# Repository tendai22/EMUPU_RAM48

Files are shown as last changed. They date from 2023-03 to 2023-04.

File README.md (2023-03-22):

# EMUPU_RAM48
A retroCPU companion board, inspired by Denno-Densetsu EMUZ80 and its related/inspired works

PIC18F, 128kB SRAMといにしえのCPUを用いて、いにしえのCPUを動作させます。Z80ピンアサインを基本にしていますが、基板上部にレトロCPUを載せた小型基板(メザニン基板)を繋ぐことで、Z80以外のさまざまなCPUに対応できるようにします。

PIC18F57Q43のCLC(Configurable Logic Cell)を活かしてCPU/SRAM制御信号を生成することで、最高パフォーマンスを目指します。そのために、アクセスタイム12nsのSRAMを使用します。48pin PICでピン数を稼いで、SPI経由でSDカードを駆動することも目標とする。

回路的には[奥江さんの作品](https://github.com/satoshiokue/SuperMEZ80)に由来しています。但し、奥江さんの作品は[EMUZ80](https://github.com/vintagechips/emuz80)基板をベースにしておりメザニン基板上でSRAMとCPUを搭載するのに対し、この試みでは、SRAMをメイン基板に移し、メザニン基板上にはCPUだけを載せるようにしています。

## コンセプト

* レトロCPUのプログラムはSRAM上に展開する。
* レトロCPUのプログラム展開はPICが行う(ブートローディング機能)。
* レトロCPUからSRAMへのアクセスは、/OE, /WEで行うが、これらの信号はPICのCLCで生成する。
* レトロCPUのI/OアクセスはPICで受ける。タイミング合わせのため、バスサイクルを延長する。
* バスサイクルの延長: Z80の場合は/WAIT信号による。68008の場合は/DTACKを使う。いずれもCLCでソフトウェア介在なしで発生する。
* I/O空間にはシリアル(Data, Status)、ディスクアクセス用のポートを置く。
* 割り込み発生とアクノレッジサイクル対応もPICが行う。

## CLCの使い方

SRAMの/OE, /WEをCLCでハード的に(ソフトを介在する必要なしに)発生する。これにより、SRAMアクセス時はソフト処理のオーバヘッドなしにZ80のメモリサイクルを実行させることができる。

I/Oアクセスは従来通り、PICがZ80のI/Oサイクルに対応する。/IORQで/WAIT信号をアサートし、I/OアクセスでCPUはアクセスを延長する。このやり方により、I/Oアクセスは時間が掛かる(数us～10数us程度)が、Z80プログラムの実行速度の大部分はメモリアクセスによるため、パフォーマンス低下の影響は小さいとしてよいだろう。

PIC側ソフトでI/O処理を行い、完了すると/BUSRQを立てて/WAITをネゲートする。CPUがI/Oサイクルを終了する(/IORQを監視している)と、/BUSRQを落としてCPUの実行を再開させる。/BUSRQをこのように使うことで、PIC側のサイクル終了処理を完了させるまでZ80を次のサイクルに入れないようにすることができる。

* CLCは3個使用する。それぞれで /OE, /WE, /WAITを発生する。
* /OE = /MREQ == 0 && /RD == 0 && /RFSH == 1
* /WE = /MREQ == 0 && /RD == 1 && /RFSH == 1
* /WAIT は/IORQの下りエッジでセットされるD-FFの/Q出力をあてる。

CLC1,2,3を使用し、それぞれの出力を、CLC1: /OE, CLC2: /WE, CLC3: /WAIT と割り当てる。

CLC1, CLC2は 4input AND, CLC3は D-FF with R/S とする。

CLC全セルの入力は最大8本で、RA/RCから4本、RB/RDから4本割り当てることができる。RE, RFからの割り当てはできない。この制約を考慮すると、
* Z80の出力, PICの入力: RA, RBに割り当てる。
* Z80の入力, PICの出力: RE(ソフト制御), RA or RB (CLC出力)

に割り当てるという原則ができる。

CLC1, CLC2の入力は、/MREQ, /RD, /RFSH であり、それぞれ RA1, RA4, RA5 に接続する。

CLC3の D-FF CLKに /IORQ を割り当てる。/IORQ を RA0に接続する。D-FF /Q出力を /WAITにつなぐ。/WAITをRB7に接続する。

以上を考慮して、Z80の制御線をPICに以下のように割り当てた(Rev.002.1)。

|PIC signal|Z80 signal|
|--|--|
|RA0|IORQ|
|RA1|MREQ|
|RA2|SRAM WE|
|RA3|CLK|
|RA4|SRAM OE|
|RA5|RD|
|RB7|WAIT|
|RB6|TEST(ソフト駆動用)|
|RB5|M1|
|RB4|RFSH|
|RE0|BUSRQ|
|RE1|RESET|
|RE2|INT|

RB0-3はSDカード接続用に割り当てた。

> Z80版では/RDが/MREQの下りエッジよりも先に確定することを前提としている。データシート的にはこの前提が成立するかどうか不明である。この前提が成立しない場合、リードサイクルの最初に /WEに一瞬グリッジが発生する可能性がある。このグリッジによりSRAM中のデータが破壊される可能性がある。ライトサイクルは本来/WR信号でタイミングを取る。この場合、RD7に/WR信号を繋いで、/WE信号のゲート(CLC2)入力に/WR信号を入れることになる。

## ブートローディング

SRAMのアドレスバスにPICのRD0-7, RF0-7を割り当てできている。よって、任意の位置にプログラムを転送することができる。PICからSRAMへの書き込みは、
* アドレスをRD, RFに出力し、
* データをRCに出力し、
* /WEをアサートし、ネゲートする

ことで実現できる。

> PICがアドレスバスにピン割り当てできない場合は、リセット解除後のメモリリードサイクルを捕まえて、0x21, (デスティネーション下位), (デスティネーション上位), 0x36, (書き込みバイト１バイト目), 0x23, 0x36, (書き込みバイト2バイト目), 0x23, 0x36, ... と順次バイトを置いてゆくことでSRAMにデータを転送することができる(「命令置き」)。

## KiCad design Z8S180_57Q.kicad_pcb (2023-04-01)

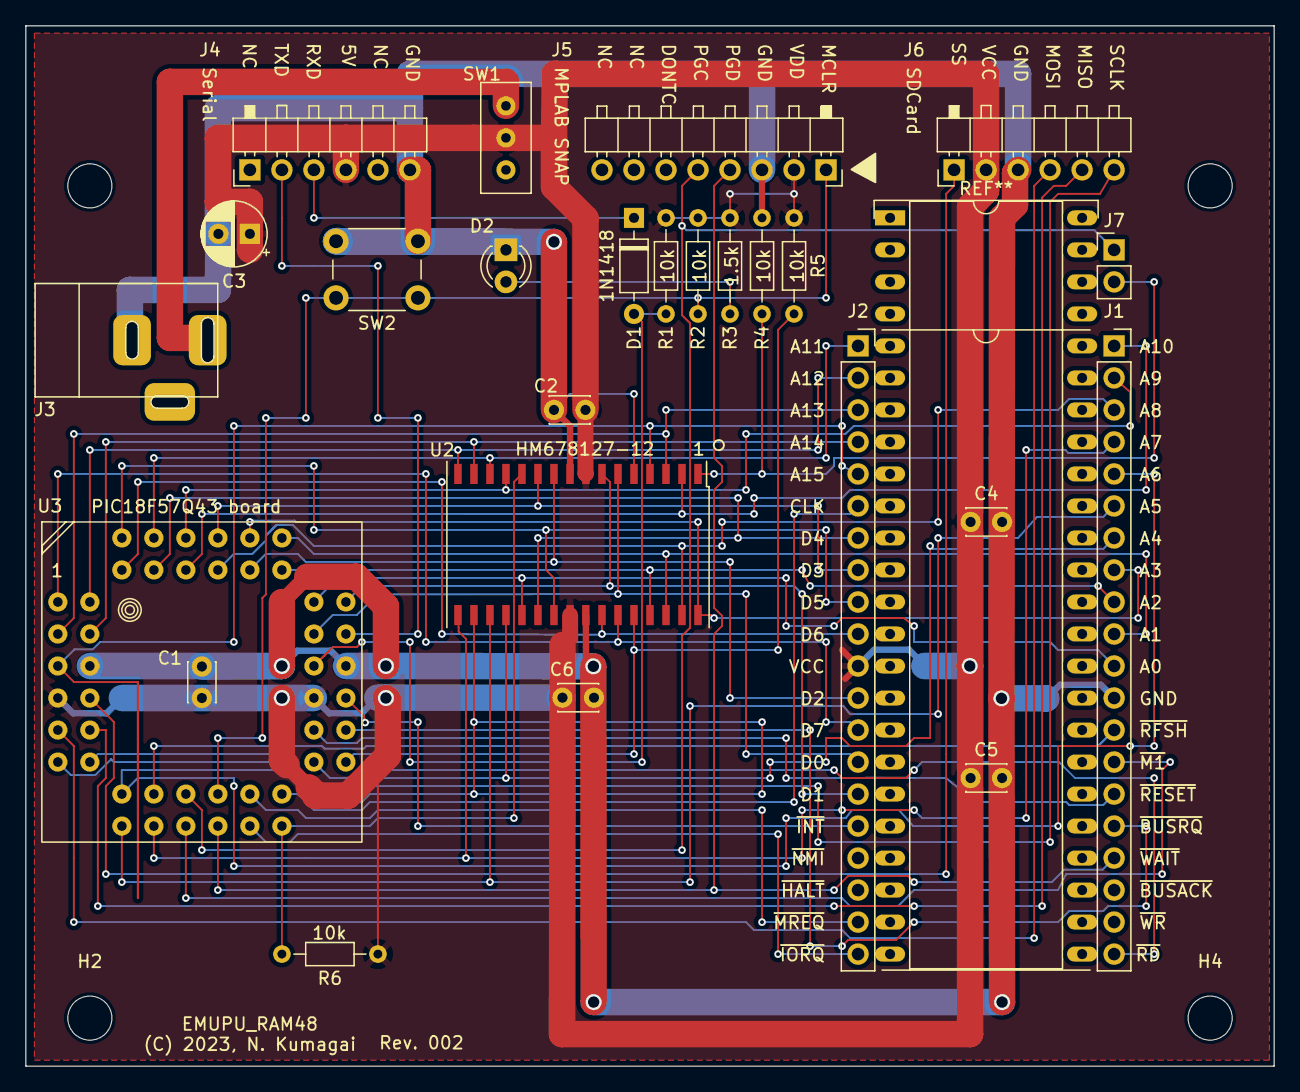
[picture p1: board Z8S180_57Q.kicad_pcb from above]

Board: 2 copper layers, 99.1 x 82.5 mm, 29 parts (0 on the bottom side), 50 nets.

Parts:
C1, C2, C4, C5, C6: 0.1uF; C_Disc_D3.0mm_W2.0mm_P2.50mm
C3: 10uF; CP_Radial_D5.0mm_P2.50mm
D1: 1N4148; D_DO-35_SOD27_P7.62mm_Horizontal
D2: LED; LED_D3.0mm
H2, H4, H5, H6: MountingHole; MountingHole_3.5mm
J1, J2: Conn_01x20_Socket; PinSocket_1x20_P2.54mm_Vertical
J3: Barrel_Jack_Switch; BARREL_JACK
J4, J6: Conn_01x06_Pin; PinHeader_1x06_P2.54mm_Horizontal_NoFeet
J5: Conn_01x08_Pin; PinHeader_1x08_P2.54mm_Rev_Horizontal_Nofoot
J7: Conn_01x02_Pin; PinHeader_1x02_P2.54mm_Vertical
R1, R2, R4, R5, R6: 10k; R_Axial_DIN0204_L3.6mm_D1.6mm_P7.62mm_Horizontal
R3: 1.5k; R_Axial_DIN0204_L3.6mm_D1.6mm_P7.62mm_Horizontal
SW1: SW_SPDT; PowerSW_for_SBC_series
SW2: SW_SPST; SW_PUSH_6mm_H4.3mm
U2: HM678127_SOJ32_Arranged; TSOP-II-32_21.0x10.2mm_P1.27mm
U3: PIC18F57Q43-IPT; Quad-2x6

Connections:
/A0: J1.11, U2.21 (A13), U3.36 (RF0)
/A1: J1.10, U2.30 (A6), U3.37 (RF1)
/A2: J1.9, U2.29 (A7), U3.38 (RF2)
/A3: J1.8, U2.32 (A11), U3.39 (RF3)
/A4: J1.7, U2.20 (A14), U3.12 (RF4)
/A5: J1.6, U2.19 (A15), U3.13 (RF5)
/A6: J1.5, U2.18 (A16), U3.14 (RF6)
/A7: J1.4, U2.17 (A8), U3.15 (RF7)
/A8: J1.3, U2.31 (A12), U3.42 (RD0)
/A9: J1.2, U2.13 (A0), U3.43 (RD1)
/A10: J1.1, U2.2 (A5), U3.44 (RD2)
/A11: J2.1, U2.14 (A1), U3.45 (RD3)
/A12: J2.2, U2.16 (A9), U3.2 (RD4)
/A13: J2.3, U2.3 (A4), U3.3 (RD5)
/A14: J2.4, U2.15 (A2), U3.4 (RD6)
/A15: J2.5, U2.4 (A3), U3.5 (RD7)
/A16: J7.2, R4.1, U2.1 (A10)
/CLK: J2.6, U3.24 (RA3)
/D0: J2.14, U2.6 (IO0), U3.34 (RC0)
/D1: J2.15, U2.7 (IO1), U3.35 (RC1)
/D2: J2.12, U2.10 (IO2), U3.40 (RC2)
/D3: J2.8, U2.11 (IO3), U3.41 (RC3)
/D4: J2.7, U2.22 (IO4), U3.46 (RC4)
/D5: J2.9, U2.23 (IO5), U3.47 (RC5)
/D6: J2.10, U2.26 (IO6), U3.48 (RC6)
/D7: J2.13, U2.27 (IO7), U3.1 (RC7)
/TEST: J5.5, J7.1, U3.18 (RB6/ICSPCLK)
/~BUSRQ: J1.16, U3.27 (RE0)
/~INT: J2.16, U3.29 (RE2)
/~IORQ: J2.20, U3.21 (RA0)
/~M1: J1.14, U3.17 (RB5)
/~MREQ: J2.19, U3.22 (RA1)
/~RD: J1.20, U3.26 (RA5)
/~RESET: J1.15, U3.28 (RE1)
/~RFSH: J1.13, U3.16 (RB4)
/~WAIT: J1.17, J5.4, U3.19 (RB7/ICSPDAT)
GND: C1.2, C2.2, C3.2, C4.2, C5.2, C6.2, D2.1 (K), J1.12, J3.2, J4.6, J5.3, J6.3, R4.2, SW2.2 (B), U2.5 (~CS), U2.9 (VSS), U2.25 (VSSO), U3.6 (VSS), U3.31 (VSS)
unnamed: D1.2 (A), R1.2, U3.32 (RA7)
unnamed: D1.1 (K), J4.3
unnamed: D2.2 (A), R3.2
unnamed: J4.2, U3.33 (RA6)
unnamed: J5.1, R2.2, SW2.1 (A), U3.20 (~MCLR)
unnamed: J6.1, U3.8 (RB0)
unnamed: J6.4, U3.9 (RB1)
unnamed: J6.5, U3.10 (RB2)
unnamed: J6.6, U3.11 (RB3)
unnamed: J3.1, SW1.3 (C)
unnamed: R5.2, U2.28 (~OE), U3.25 (RA4)
unnamed: R6.2, U2.12 (~WE), U3.23 (RA2)
VCC: C1.1, C2.1, C3.1, C4.1, C5.1, C6.1, J2.11, J4.4, J5.2, J6.2, R1.1, R2.1, R3.1, R5.1, R6.1, SW1.2 (B), U2.8 (VCC), U2.24 (VCCO), U3.7 (VDD), U3.30 (VDD)

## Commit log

2023-02-25 Initial, but checked, finished, ready to send Garber files
    [EMUPU_RAM.csv, EMUPU_RAM.kicad_pcb, EMUPU_RAM.kicad_sch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]
2023-02-25 Adjusting rule, described in Kosakas book, need some refinements
    [EMUPU_RAM.kicad_pcb, EMUPU_RAM.kicad_sch]
2023-02-25 Add Beta-filling, archive ZIP file
    [EMUPU_RAM.kicad_pcb]
2023-02-25 Generate garber files
    [EMUPU_RAM-B_Cu.gbl, EMUPU_RAM-B_Mask.gbs, EMUPU_RAM-B_Silkscreen.gbo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]
2023-02-26 Add Z80 label, RBx jumpers, garbers, ZIP
    [EMUPU_RAM-B_Cu.gbl, EMUPU_RAM-B_Mask.gbs, EMUPU_RAM-B_Silkscreen.gbo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]
2023-02-26 Ordered version, designated as Rev. 001
    [EMUPU_RAM-B_Cu.gbl, EMUPU_RAM-B_Mask.gbs, EMUPU_RAM-B_Silkscreen.gbo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]
2023-02-26 EMUPC_RAM40 start, add kicad_sch and kicad_pcb files
    [EMUPU_RAM40.kicad_pcb, EMUPU_RAM40.kicad_sch]
2023-02-27 Add pdf schematic files
2023-02-27 ram40 powerlines comleted, ready to start autoroute
    [EMUPU_RAM40.kicad_pcb]
2023-02-27 before autorouting 2nd version, 48pin dummy socket included
    [EMUPU_RAM40.kicad_pcb]
2023-02-27 3rd before-freerouting, add Z80 pin-names, beta-border, and narrower board size and rearrangement of parts
    [EMUPU_RAM40.kicad_pcb, EMUPU_RAM40.kicad_sch]
2023-02-27 Loose some unconnected VCC/GND, move some Rs
    [EMUPU_RAM40.kicad_pcb]
2023-02-27 Correct Serial 6pin connections
    [EMUPU_RAM40.kicad_pcb]
2023-02-27 fix some on schematics
    [EMUPU_RAM40.kicad_sch]
2023-02-27 Fix J4 silk, add pin names on J4, J5, fix vcc connection bottom of SRAM
    [EMUPU_RAM40.kicad_pcb]
2023-02-28 EMUPU_RAM40 PCB finished
    [EMUPU_RAM40.kicad_pcb]
2023-02-28 fix garber files, order it to JLCPCB
    [EMUPU_RAM40-B_Cu.gbl, EMUPU_RAM40-B_Mask.gbs, EMUPU_RAM40-B_Silkscreen.gbo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]
2023-02-28 schematic pdf, Rev100.pdf
2023-02-28 EMUPU_RAM68k schematic and 68008 device symbol
    [EMUPU_RAM68k.kicad_pcb, EMUPU_RAM68k.kicad_sch]
2023-02-28 Add RAM68k schematic pdf file
2023-03-03 Exchange RD6 and RD7, add .gitignore
    [EMUPU_RAM68k.kicad_sch]
2023-03-04 ram40_68k8 for B-board Rev. 002, just rebulided.
    [EMUPU_RAM68k.kicad_sch]
2023-03-09 Cut BR-PIC RD5, and add TEST pin
    [EMUPU_RAM68k.kicad_sch]
2023-03-16 Fix BARREL_JACK footpattern, modify schematic file (Rev002), pcb file fix ongoing
    [EMUPU_RAM.kicad_pcb, EMUPU_RAM.kicad_sch]
2023-03-16 New (Rev002) netlist just imported
    [EMUPU_RAM.kicad_pcb]
2023-03-16 EMUPU_RAM48_Rev002. pcb modifying completed
    [CLC_logic.kicad_pcb, CLC_logic.kicad_sch, EMUPU_RAM.kicad_pcb]
2023-03-16 RAM48 pcb slightly revised
    [EMUPU_RAM.kicad_pcb]
2023-03-22 change revision number in schematic file., add PDF file
    [EMUPU_RAM.kicad_sch]
2023-03-22 Describe pin assign idea in README.md
2023-03-29 slightly modified to Rev.002
    [EMUPU_RAM.kicad_pcb]
2023-04-01 Ordered JLCPCB, ram48_rev002.2
    [EMUPU_RAM-B_Cu.gbl, EMUPU_RAM-B_Mask.gbs, EMUPU_RAM-B_Silkscreen.gbo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]
2023-05-13 under construction for Rev003 done the follows * fix PowerPlug pin assignment * change /MREQ, /RD, /WR for full_direct * A jumper is assigned to SRAM CS2 (now pulled-up) * add jumpers on /MREQ, /RD, 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
    remains for the following
    * add TEST pin
    * add LEDs and resistors, including RESET, BUSACK, and HALT
    * add pull down resistors to A15-A8, as needed.* add some jumpers for SDcard controls (A9-A12)
    * add four jumpers for SDcard (A9-A12)
    After confirming 8byte rewrite and reset bootloading, I will finishes the remains.
    [EMUPU_RAM40.kicad_pcb, EMUPU_RAM40.kicad_sch]
2023-05-14 Rev003: arrange new footprints, before autorouting
    [EMUPU_RAM40.kicad_pcb, EMUPU_RAM40.kicad_sch]
2023-05-14 Rev003: autorouting done, no no-connection, but some error/warning remains
    [EMUPU_RAM40.kicad_pcb, EMUPU_RAM40.kicad_sch]
2023-05-15 Rev003: ordered to JLCPCB
    [EMUPU_RAM40-B_Cu.gbl, EMUPU_RAM40-B_Mask.gbs, EMUPU_RAM40-B_Silkscreen.gbo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]
2023-06-14 rm unnecessry files, and add Z8S180_57Q.* files
    [CLC_logic.kicad_pcb, CLC_logic.kicad_sch, EMUPU_RAM.csv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]

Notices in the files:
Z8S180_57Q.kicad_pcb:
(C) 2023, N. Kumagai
